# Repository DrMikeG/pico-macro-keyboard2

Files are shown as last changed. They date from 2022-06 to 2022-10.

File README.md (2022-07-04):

# pico-macro-keyboard2

## 2nd July 2022 ##

Successfully used the finger print scanner to enroll and recognise a fingerprint.

(See EnrollTest01 code)
```
uart = busio.UART(tx=board.GP8, rx=board.GP9, baudrate=57600)
finger = adafruit_fingerprint.Adafruit_Fingerprint(uart)
```

## 14th June 2022 ##
After some late-night messing about last night with an old arduino uno, I managed to run an LED colour changing example for the R503 - which convinced me that it was 3.3V, it wasn't dead and it was soldered correctly.

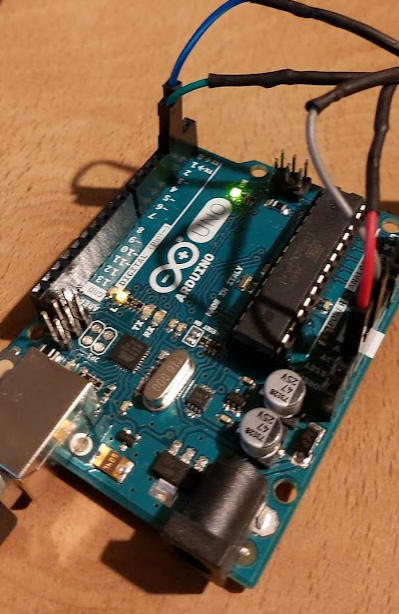
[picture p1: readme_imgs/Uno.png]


I moved back to the PICO but using UART1 on pins GP8 and GP9

Green cable(green from sensor) into pico 11
Blue cable (yellow from sensor) into pico 12

The pico recognised the sensor and I could change the LED colour to purple.



I still don't really understand why UART1 doesn't work - but I've half an idea that that is in use by MU to access the REPL.
It would make sense that an UNO needs to use software serial to access the sensor (not in pass-thru mode) because it only have 1 hardware serial
The pico has 2 UARTs - I would guess one is in use for REPL, one can connect to the sensor.

### Back to the keypad ###

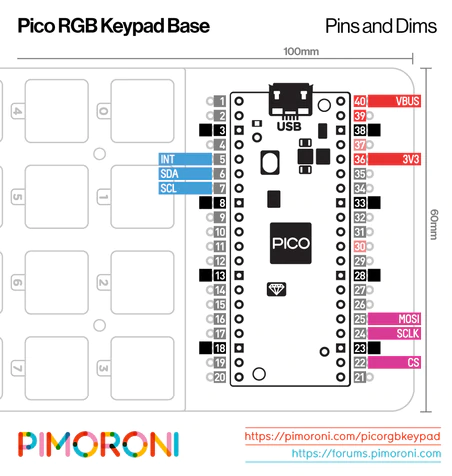
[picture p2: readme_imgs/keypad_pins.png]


Looks like the UART pins I want are free.

Looking at the schematic - the LEDs are powered from VBUS (5V), there is an IO expander powered from the 3v3, so that will compete for power with the fingerprint reader.

### Rotary Encoder ###

Not used one of these before (tended to just use potentiometers)

https://www.adafruit.com/product/377

One side has a 3 pin connector (ground and two coding pins) and the other side has two pins for a normally open switch.

```
Connect Trinket's ground to the rotary encoder's common pin.
Connect Trinket's pin #0 to the rotary encoder's "A" signal pin.
Connect Trinket's pin #2 to the rotary encoder's "B" signal pin.

These encoder signals will be "active-low". Each of these signals is a switch inside the rotary encoder. Active-low means the other end of the switch is connected to ground, such that when the switch is "closed", the pin value will read low. We will be using the Trinket's internal pull-up resistors so when the switch is "open", the pin value will read high.
```

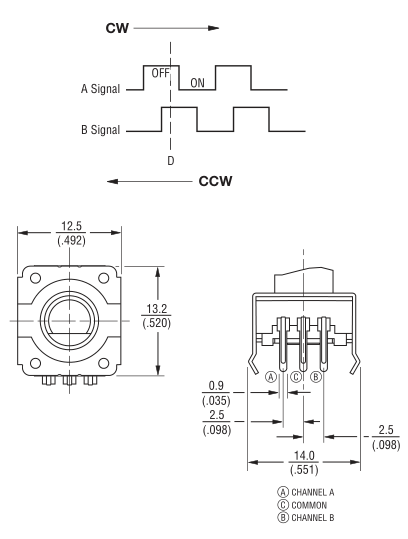
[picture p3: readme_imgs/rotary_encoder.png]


See \RotaryEncoder\Demo1\code copy.py

```
import board
import rotaryio

#ENCODER = rotaryio.IncrementalEncoder(board.A2, board.A3)
ENCODER = rotaryio.IncrementalEncoder(board.GP26, board.GP27)

# MAIN LOOP ----------------------------------------------------------------

LAST_POSITION = ENCODER.position
while True:
    POSITION = ENCODER.position
    if POSITION != LAST_POSITION:
        MOVE = POSITION - LAST_POSITION
        LAST_POSITION = POSITION
        print("Move",MOVE)
```

#### Adding a button ####
```
The button switch is connected to Trinket's pin #1. It is "active-high", meaning when the button is pressed, the pin will read as logic high. When the button is not pressed, the pin will read as logic low. (the built-in LED of the Trinket shares pin #1, the LED acts as a pull-down resistor)
```

#### Testing on the pico ####

Used the code in RotaryEncoder\Demo1\code copy.py.
No libraries needed copying in. rotaryio is native.

Can detect +1 and -1 for clockwise and anticlockwise.

Three wires onto 33, 32 and 31 (aGND, board.GP26, board.GP27)

Very simple.

## 13th June 2022 ##

I didn't have any luck out of the box using the pi pico I had setup already, so I'm going to set it up again from scratch.

https://learn.adafruit.com/getting-started-with-raspberry-pi-pico-circuitpython/circuitpython

CircuitPython 7.3.0 .UF2

Reboot holding button.
Drag and drop new .uf2 file.

```Traceback (most recent call last):
  File "code.py", line 24, in <module>
  File "adafruit_fingerprint.py", line 120, in __init__
  File "adafruit_fingerprint.py", line 136, in verify_password
  File "adafruit_fingerprint.py", line 348, in _get_packet
RuntimeError: Failed to read data from sensor
```

Checking wiring

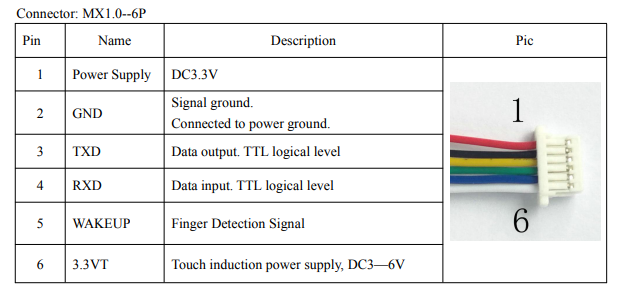
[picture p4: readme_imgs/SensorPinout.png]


There was an intermittent connection on the ground wire. I resoldered all the wires, but still nothing by the same error.

```
// For UNO and others without hardware serial, we must use software serial...
// pin #2 is IN from sensor (GREEN wire)
// pin #3 is OUT from arduino  (WHITE wire)
// Set up the serial port to use softwareserial..
SoftwareSerial mySerial(2, 3);
```
Green wire (green all the way) into pin 3
Blue wire (yellow) into pin 2

I have an arduino sketch which can control the LED ring.

It doesn't work using hardware serial on an UNO - does UNO not have hardware support?

Does the pico?

https://docs.circuitpython.org/projects/fingerprint/en/latest/api.html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

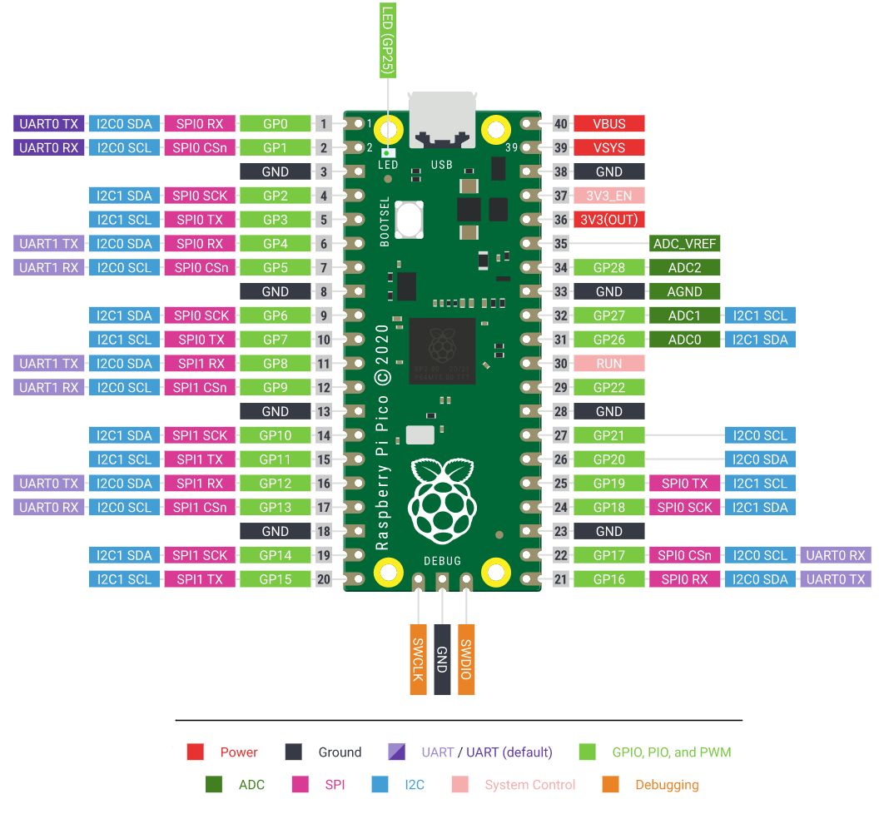
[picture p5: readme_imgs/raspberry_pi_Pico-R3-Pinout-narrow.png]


Going to have a look at the keypad for a bit.

https://dronebotworkshop.com/pi-pico-circuitpython/

### pimoroni pico rgb keypad base ###

https://github.com/pimoroni/pmk-circuitpython

You'll need to grab the latest version of Adafruit's Raspberry Pi Pico-flavoured CircuitPython, from the link below.

Download the Adafruit CircuitPython binary for Raspberry Pi Pico

Unplug your Pi Pico's micro USB cable, press and hold the BOOTSEL button on the top of Pi Pico while plugging the micro USB cable back into your computer to mount it as a drive (it should show up as RPI-RP2 or something similar).

Drag and drop the adafruit-circuitpython-raspberry_pi_pico-en_US-XXXXX.uf2 file that you downloaded onto the drive and it should reboot and load the CircuitPython firmware. The drive should now show up as CIRCUITPY.

The Adafruit DotStar LED driver library for CircuitPython is a prerequisite for this Keybow 2040 library, so you'll need to download it from GitHub at the link below, and then drop the adafruit_dotstar.py file into the lib folder on your CIRCUITPY drive.

- Reflashed Pico with latest 7.3.0 circuit python firmware
- Added \lib\adafruit_dotstar.py
- Added \lib\pmk
- renamed reactive.py to code.py
- commented out one line and enabled ``from pmk.platform.rgbkeypadbase import RGBKeypadBase as Hardware``

Lights up keys as you press them. Just works.

## 12th June 2022 ##

Prototype Panel Mount Fingerprint Sensor with Bi-Colour LED Ring (R503) (THE PI HUTSKU: 104474) with the pico.

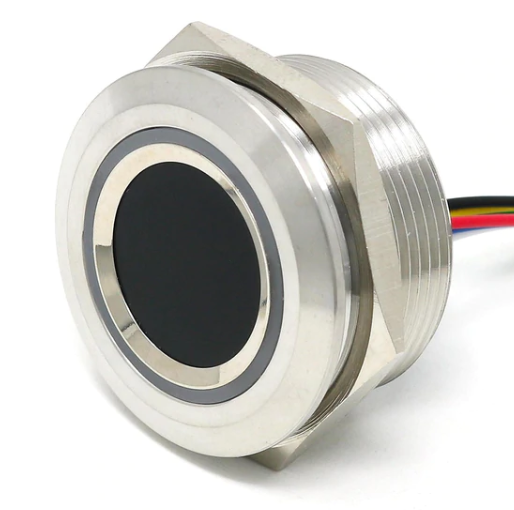
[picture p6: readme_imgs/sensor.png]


https://github.com/adafruit/Adafruit_CircuitPython_Fingerprint

https://learn.adafruit.com/adafruit-optical-fingerprint-sensor
https://learn.adafruit.com/adafruit-optical-fingerprint-sensor/circuitpython

On the "rugged" fingerprint sensor:

Red wire is connected to 3.3V for power
Black wire is connected to ground
Yellow to Microcontroller TX (data out from microcontroller)
Green to Microcontroller RX (data in from microcontroller)

```There are two I2C peripherals available, I2C0 and I2C1, two SPI peripherals, SPI0 and SPI1, and two UART peripherals, UART0 and UART1. You can assign any of these to the pins on which they are available. So for example, you can use GP0/GP1 for I2C0, and simultaneously use GP2/GP3 for I2C1, but you cannot use GP0/GP1 together with GP4/GP5 for I2C use, because they are both usable only with I2C0.```

In CircuitPython, you don't need to specify exactly which peripheral is used. As long you choose valid pins, CircuitPython will choose a free peripheral.```

To setup a UART bus, you specify the TX and RX pins. Be sure to use the UARTx pins and not the similarly named SPIx ones.

```
import board
import busio

uart = busio.UART(tx=board.GP4, rx=board.GP5)
```

I think:
Sensor yellow to 6
Sensor green to 7
Sensor red to 36
Sensor black to 38

Downloaded the version 6 circuit python bundle (not sure if the keypad supports 7 yet)?
Downloaded the version 7 circuit python bundle - let's push on.

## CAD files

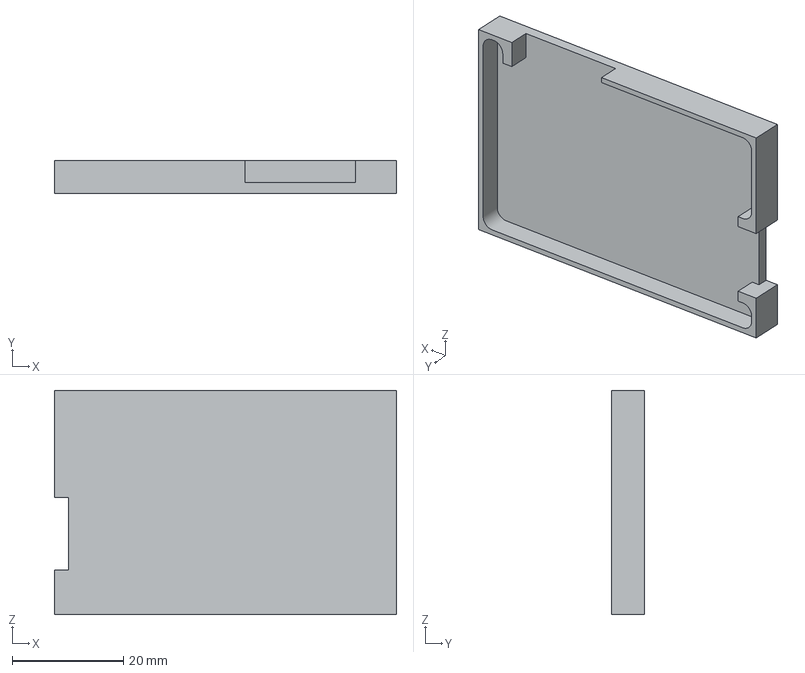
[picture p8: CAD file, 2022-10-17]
Parts/TopPlate02.3mf
61.4 x 6.00 x 40.2 mm

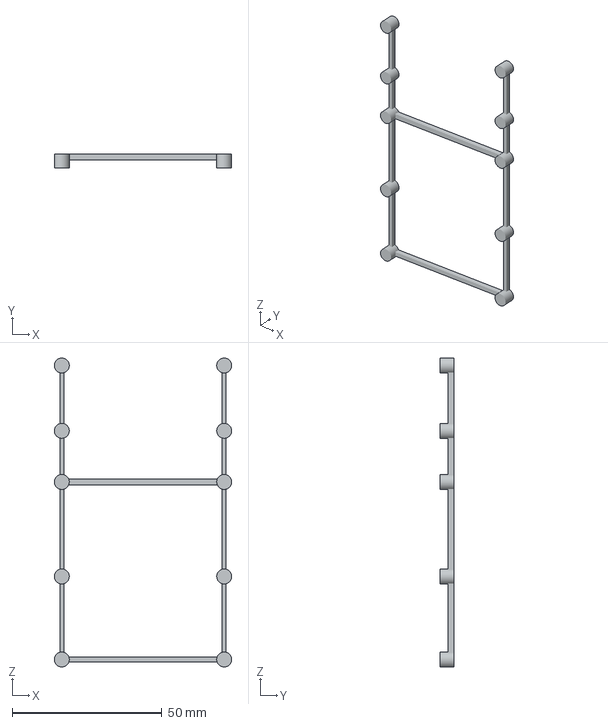
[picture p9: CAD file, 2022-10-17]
Parts/BaseRiser01.3mf
59.2 x 4.80 x 103.1 mm

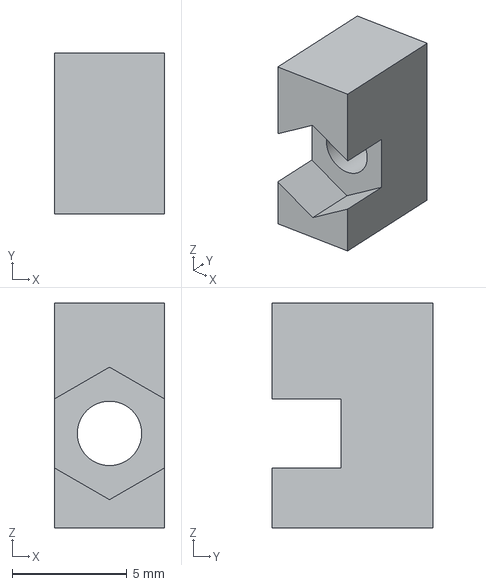
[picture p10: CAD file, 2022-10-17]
Parts/NutHolder01.3mf
4.80 x 7.00 x 9.80 mm

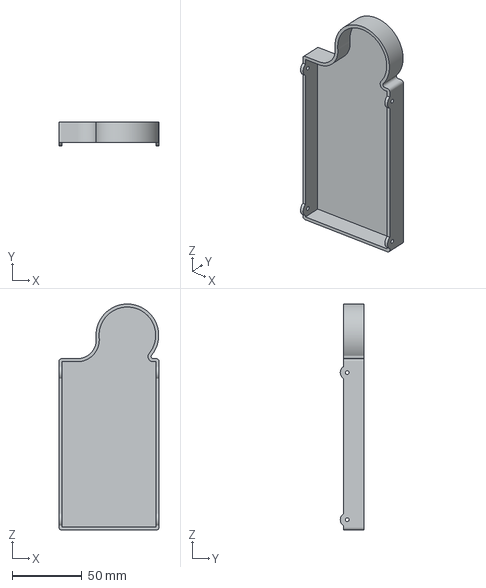
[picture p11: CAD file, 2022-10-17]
Parts/Base01.3mf
72.0 x 16.9 x 162.2 mm

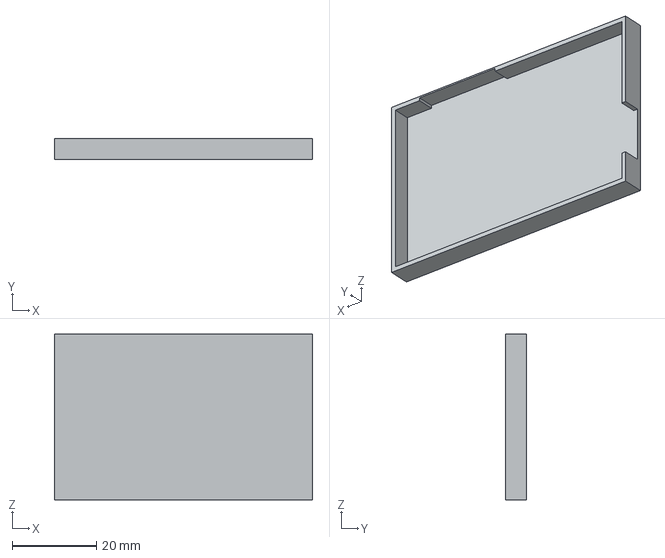
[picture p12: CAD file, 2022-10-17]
Parts/TopPlate01.3mf
61.4 x 5.00 x 39.4 mm

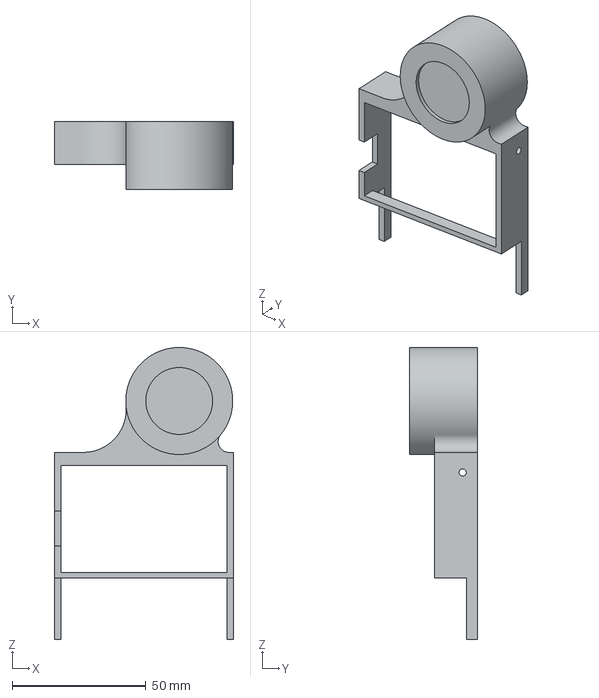
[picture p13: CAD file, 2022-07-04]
Parts/picoCover.3mf
67.0 x 25.3 x 109.2 mm

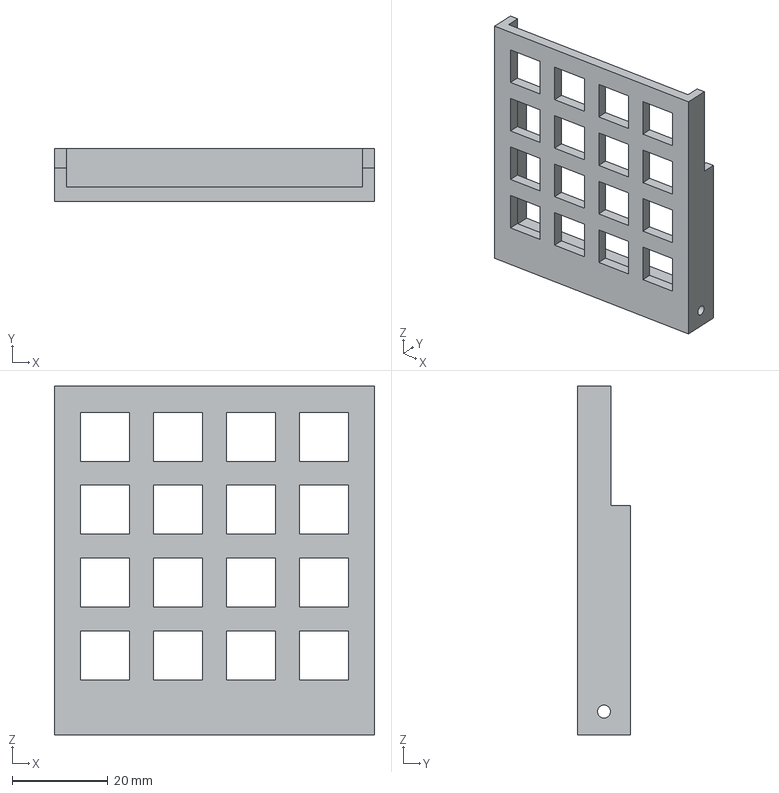
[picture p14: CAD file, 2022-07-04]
Parts/KeyCover02.3mf
67.0 x 11.0 x 73.0 mm

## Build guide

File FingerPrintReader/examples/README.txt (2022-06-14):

This bundle contains two folders, one each for CircuitPython 6.x and CircuitPython 7.x. You must use the files that match the version of CircuitPython you're using, e.g. if you are using CircuitPython 6, you will copy the files from the CircuitPython 6.x folder to your CIRCUITPY drive.

To use this project bundle, simply copy the contents of the CircuitPython version folder you're using from the zip file to your CIRCUITPY drive.
Contents in each version include:
* the code.py file
* the lib/ folder and all of its contents (including subfolders and .mpy or .py files)
* any assets (such as images, sounds, etc.)

NOTE: This will replace the current code.py, and the lib folder and its contents. Back up any desired code before copying these files!

 This zip was downloaded from https://learn.adafruit.com/adafruit-optical-fingerprint-sensor/circuitpython on June 13, 2022.

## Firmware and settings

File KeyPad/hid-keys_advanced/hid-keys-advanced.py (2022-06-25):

# SPDX-FileCopyrightText: 2021 Sandy Macdonald
#
# SPDX-License-Identifier: MIT

# An advanced example of how to set up a HID keyboard.

# There are three layers, selected by pressing and holding key 0 (bottom left),
# then tapping one of the coloured layer selector keys above it to switch layer.

# The layer colours are as follows:

#  * layer 1: pink: numpad-style keys, 0-9, delete, and enter.
#  * layer 2: blue: sends strings on each key press
#  * layer 3: media controls, rev, play/pause, fwd on row one, vol. down, mute,
#             vol. up on row two

# You'll need to connect Keybow 2040 to a computer, as you would with a regular
# USB keyboard.

# Drop the `pmk` folder
# into your `lib` folder on your `CIRCUITPY` drive.

# NOTE! Requires the adafruit_hid CircuitPython library also!

import time
from pmk import PMK
#from pmk.platform.keybow2040 import Keybow2040 as Hardware          # for Keybow 2040
from pmk.platform.rgbkeypadbase import RGBKeypadBase as Hardware  # for Pico RGB Keypad Base

import usb_hid
from adafruit_hid.keyboard import Keyboard
from adafruit_hid.keyboard_layout_us import KeyboardLayoutUS
from adafruit_hid.keycode import Keycode

from adafruit_hid.consumer_control import ConsumerControl
from adafruit_hid.consumer_control_code import ConsumerControlCode

# Set up Keybow
keybow = PMK(Hardware())
keys = keybow.keys

# Set up the keyboard and layout
keyboard = Keyboard(usb_hid.devices)
layout = KeyboardLayoutUS(keyboard)

# Set up consumer control (used to send media key presses)
consumer_control = ConsumerControl(usb_hid.devices)

# Our layers. The key of item in the layer dictionary is the key number on
# Keybow to map to, and the value is the key press to send.

# Note that keys 0-3 are reserved as the modifier and layer selector keys
# respectively.

layer_1 =     {4: Keycode.ZERO,
               5: Keycode.ONE,
               6: Keycode.FOUR,
               7: Keycode.SEVEN,
               8: Keycode.DELETE,
               9: Keycode.TWO,
               10: Keycode.FIVE,
               11: Keycode.EIGHT,
               12: Keycode.ENTER,
               13: Keycode.THREE,
               14: Keycode.SIX,
               15: Keycode.NINE}

layer_2 =     {7: "pack ",
               11: "my ",
               15: "box ",
               6: "with ",
               10: "five ",
               14: "dozen ",
               5: "liquor ",
               9: "jugs "}

layer_3 =     {6: ConsumerControlCode.VOLUME_DECREMENT,
               7: ConsumerControlCode.SCAN_PREVIOUS_TRACK,
               10: ConsumerControlCode.MUTE,
               11: ConsumerControlCode.PLAY_PAUSE,
               14: ConsumerControlCode.VOLUME_INCREMENT,
               15: ConsumerControlCode.SCAN_NEXT_TRACK}

layers =      {1: layer_1,
               2: layer_2,
               3: layer_3}

# Define the modifier key and layer selector keys
modifier = keys[0]

selectors =   {1: keys[1],
               2: keys[2],
               3: keys[3]}

# Start on layer 1
current_layer = 1

# The colours for each layer
noZero = 32
colours = {1: (noZero, 0, noZero),
           2: (0, noZero, noZero),
           3: (noZero, noZero, 0)}

layer_keys = range(4, 16)

# Set the LEDs for each key in the current layer
for k in layers[current_layer].keys():
    keys[k].set_led(*colours[current_layer])

# To prevent the strings (as opposed to single key presses) that are sent from
# refiring on a single key press, the debounce time for the strings has to be
# longer.
short_debounce = 0.03
long_debounce = 0.15
debounce = 0.03
fired = False

while True:
    # Always remember to call keybow.update()!
    keybow.update()

    # This handles the modifier and layer selector behaviour
    if modifier.held:
        # Give some visual feedback for the modifier key
        keys[0].led_off()

        # If the modifier key is held, light up the layer selector keys
        for layer in layers.keys():
            keys[layer].set_led(*colours[layer])

            # Change layer if layer key is pressed
            if current_layer != layer:
                if selectors[layer].pressed:
                    current_layer = layer

                    # Set the key LEDs first to off, then to their layer colour
                    for k in layer_keys:
                        keys[k].set_led(0, 0, 0)

                    for k in layers[layer].keys():
                        keys[k].set_led(*colours[layer])

    # Turn off the layer selector LEDs if the modifier isn't held
    else:
        for layer in layers.keys():
            keys[layer].led_off()

        # Give some visual feedback for the modifier key
        keys[0].set_led(0, 255, 25)

    # Loop through all of the keys in the layer and if they're pressed, get the
    # key code from the layer's key map
    for k in layers[current_layer].keys():
        if keys[k].pressed:
            key_press = layers[current_layer][k]

            # If the key hasn't just fired (prevents refiring)
            if not fired:
                fired = True

                # Send the right sort of key press and set debounce for each
                # layer accordingly (layer 2 needs a long debounce)
                if current_layer == 1:
                    debounce = short_debounce
                    keyboard.send(key_press)
                elif current_layer == 2:
                    debounce = long_debounce
                    layout.write(key_press)
                elif current_layer == 3:
                    debounce = short_debounce
                    consumer_control.send(key_press)

    # If enough time has passed, reset the fired variable
    if fired and time.monotonic() - keybow.time_of_last_press > debounce:
        fired = False

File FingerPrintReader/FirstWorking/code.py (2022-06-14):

# SPDX-FileCopyrightText: 2021 ladyada for Adafruit Industries
# SPDX-License-Identifier: MIT

import time
import board
import busio
from digitalio import DigitalInOut, Direction
import adafruit_fingerprint

led = DigitalInOut(board.LED)
led.direction = Direction.OUTPUT
#uart = busio.UART(board.TX, board.RX, baudrate=57600)
uart = busio.UART(tx=board.GP8, rx=board.GP9, baudrate=57600)

# If using with a computer such as Linux/RaspberryPi, Mac, Windows with USB/serial converter:
# import serial
# uart = serial.Serial("/dev/ttyUSB0", baudrate=57600, timeout=1)

# If using with Linux/Raspberry Pi and hardware UART:
# import serial
# uart = serial.Serial("/dev/ttyS0", baudrate=57600, timeout=1)

finger = adafruit_fingerprint.Adafruit_Fingerprint(uart)

##################################################


def get_fingerprint():
    """Get a finger print image, template it, and see if it matches!"""
    print("Waiting for image...")
    while finger.get_image() != adafruit_fingerprint.OK:
        pass
    print("Templating...")
    if finger.image_2_tz(1) != adafruit_fingerprint.OK:
        return False
    print("Searching...")
    if finger.finger_search() != adafruit_fingerprint.OK:
        return False
    return True


# pylint: disable=too-many-branches
def get_fingerprint_detail():
    """Get a finger print image, template it, and see if it matches!
    This time, print out each error instead of just returning on failure"""
    print("Getting image...", end="", flush=True)
    i = finger.get_image()
    if i == adafruit_fingerprint.OK:
        print("Image taken")
    else:
        if i == adafruit_fingerprint.NOFINGER:
            print("No finger detected")
        elif i == adafruit_fingerprint.IMAGEFAIL:
            print("Imaging error")
        else:
            print("Other error")
        return False

    print("Templating...", end="", flush=True)
    i = finger.image_2_tz(1)
    if i == adafruit_fingerprint.OK:
        print("Templated")
    else:
        if i == adafruit_fingerprint.IMAGEMESS:
            print("Image too messy")
        elif i == adafruit_fingerprint.FEATUREFAIL:
            print("Could not identify features")
        elif i == adafruit_fingerprint.INVALIDIMAGE:
            print("Image invalid")
        else:
            print("Other error")
        return False

    print("Searching...", end="", flush=True)
    i = finger.finger_fast_search()
    # pylint: disable=no-else-return
    # This block needs to be refactored when it can be tested.
    if i == adafruit_fingerprint.OK:
        print("Found fingerprint!")
        return True
    else:
        if i == adafruit_fingerprint.NOTFOUND:
            print("No match found")
        else:
            print("Other error")
        return False


# pylint: disable=too-many-statements
def enroll_finger(location):
    """Take a 2 finger images and template it, then store in 'location'"""
    for fingerimg in range(1, 3):
        if fingerimg == 1:
            print("Place finger on sensor...", end="", flush=True)
        else:
            print("Place same finger again...", end="", flush=True)

        while True:
            i = finger.get_image()
            if i == adafruit_fingerprint.OK:
                print("Image taken")
                break
            if i == adafruit_fingerprint.NOFINGER:
                print(".", end="", flush=True)
            elif i == adafruit_fingerprint.IMAGEFAIL:
                print("Imaging error")
                return False
            else:
                print("Other error")
                return False

        print("Templating...", end="", flush=True)
        i = finger.image_2_tz(fingerimg)
        if i == adafruit_fingerprint.OK:
            print("Templated")
        else:
            if i == adafruit_fingerprint.IMAGEMESS:
                print("Image too messy")
            elif i == adafruit_fingerprint.FEATUREFAIL:
                print("Could not identify features")
            elif i == adafruit_fingerprint.INVALIDIMAGE:
                print("Image invalid")
            else:
                print("Other error")
            return False

        if fingerimg == 1:
            print("Remove finger")
            time.sleep(1)
            while i != adafruit_fingerprint.NOFINGER:
                i = finger.get_image()

    print("Creating model...", end="", flush=True)
    i = finger.create_model()
    if i == adafruit_fingerprint.OK:
        print("Created")
    else:
        if i == adafruit_fingerprint.ENROLLMISMATCH:
            print("Prints did not match")
        else:
            print("Other error")
        return False

    print("Storing model #%d..." % location, end="", flush=True)
    i = finger.store_model(location)
    if i == adafruit_fingerprint.OK:
        print("Stored")
    else:
        if i == adafruit_fingerprint.BADLOCATION:
            print("Bad storage location")
        elif i == adafruit_fingerprint.FLASHERR:
            print("Flash storage error")
        else:
            print("Other error")
        return False

    return True


##################################################


def get_num():
    """Use input() to get a valid number from 1 to 127. Retry till success!"""
    i = 0
    while (i > 127) or (i < 1):
        try:
            i = int(input("Enter ID # from 1-127: "))
        except ValueError:
            pass
    return i


while True:
    print("----------------")
    if finger.read_templates() != adafruit_fingerprint.OK:
        raise RuntimeError("Failed to read templates")
    print("Fingerprint templates:", finger.templates)
    print("e) enroll print")
    print("f) find print")
    print("d) delete print")
    print("----------------")

    #color: 1=red, 2=blue, 3=purple 
    # mode: 1-breathe, 2-flash, 3-on, 4-off, 5-fade_on, 6-fade-off 
    finger.set_led(color=3, mode=2)

    c = input("> ")

    if c == "e":
        enroll_finger(get_num())
    if c == "f":
        if get_fingerprint():
            print("Detected #", finger.finger_id, "with confidence", finger.confidence)
        else:
            print("Finger not found")
    if c == "d":
        if finger.delete_model(get_num()) == adafruit_fingerprint.OK:
            print("Deleted!")
        else:
            print("Failed to delete")

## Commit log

2022-07-04 Combined fingerprint reader with macropad setup for single layer. Designing parts for housing.
    [KeyCover02.3mf, picoCover.3mf]
2022-10-17 Saving parts
    [Base01.3mf, BaseRiser01.3mf, CaseAsm1.cfg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]
